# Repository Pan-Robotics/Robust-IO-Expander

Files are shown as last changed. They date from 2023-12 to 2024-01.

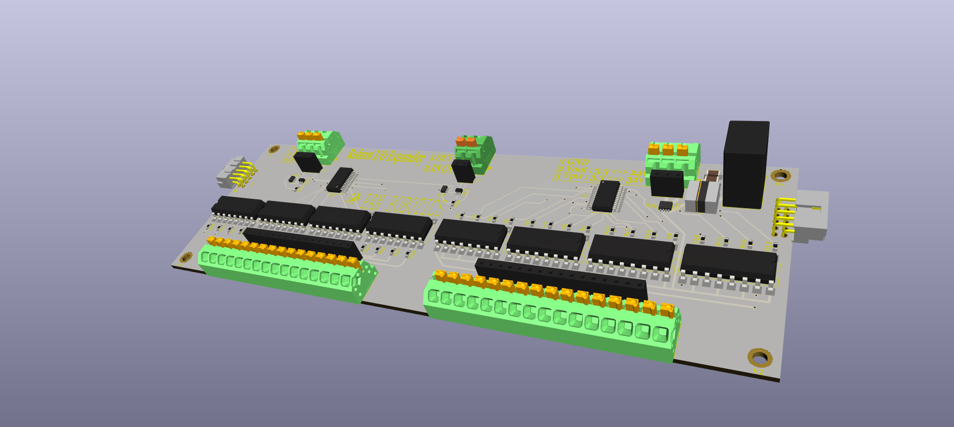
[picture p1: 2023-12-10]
Robust IO Expander/Docs/Photos/3D 4.png

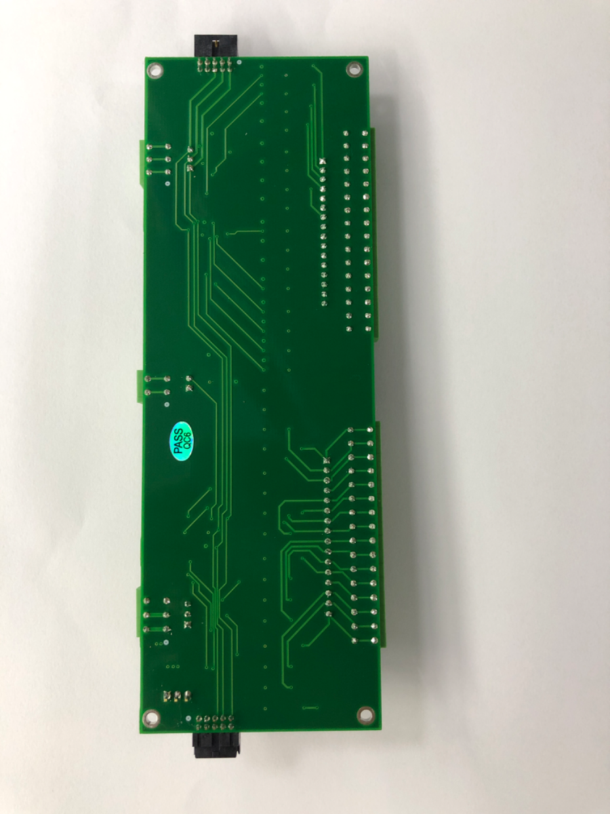
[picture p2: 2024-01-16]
Robust IO Expander/Docs/Photos/IO-Expander 3-Back.jpg

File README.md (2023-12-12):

# Robust-IO-Expander

    1. Dual MCP23S17 ICs: Harness the power of two MCP23S17 16-Bit I/O Expander ICs – one dedicated for inputs, ensuring robust data acquisition, 
    and the other exclusively for outputs, enabling precise device control.
    
    2. Galvanic Isolation with Opto Switches: Prioritize safety in your projects. Our I/O Expansion Module integrates opto switches for galvanic isolation, 
    shielding your electronics from voltage spikes and surges, ensuring secure and reliable operation.
    
    3. SPI Interface: Interact effortlessly with your system via the SPI interface. This streamlined communication protocol ensures swift and efficient data exchange, 
    allowing you to focus on the heart of your project.
    
    4. Connector Options: Tailor the module to your needs. Choose between 2.54mm header connectors for easy integration into your existing setups or Push terminals for a robust, secure connection. 
    The choice is yours, ensuring seamless compatibility with your specific project requirements.
    
    5. Effortless Expansion: Need more I/O pins? No problem! Our module is stackable, facilitating seamless expansion. 
    Connect multiple modules effortlessly to scale your projects without limitations, providing endless opportunities for your creative endeavors.
    
    6. Unparalleled Flexibility: Whether you're orchestrating automation systems, developing cutting-edge robotics, or creating interactive art installations, 
    the versatility of our I/O Expansion Module amplifies your creativity. Control motors, sensors, LEDs, and various devices effortlessly, opening doors to innovative projects.

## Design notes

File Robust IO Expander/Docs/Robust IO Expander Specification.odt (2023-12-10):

Introducing our state-of-the-art I/O Expansion Module, designed to empower your projects with seamless control and unparalleled safety. Whether you're a hobbyist, engineer, or DIY enthusiast, this module is your gateway to limitless possibilities.

Key Features:

1. Dual MCP23S17 ICs: Harness the power of two MCP23S17 16-Bit I/O Expander ICs – one dedicated for inputs, ensuring robust data acquisition, and the other exclusively for outputs, enabling precise device control.
2. Galvanic Isolation with Opto Switches: Prioritize safety in your projects. Our I/O Expansion Module integrates opto switches for galvanic isolation, shielding your electronics from voltage spikes and surges, ensuring secure and reliable operation.
3. SPI Interface: Interact effortlessly with your system via the SPI interface. This streamlined communication protocol ensures swift and efficient data exchange, allowing you to focus on the heart of your project.
4. Connector Options: Tailor the module to your needs. Choose between 2.54mm header connectors for easy integration into your existing setups or Push terminals for a robust, secure connection. The choice is yours, ensuring seamless compatibility with your specific project requirements.
5. Effortless Expansion: Need more I/O pins? No problem! Our module is stackable, facilitating seamless expansion. Connect multiple modules effortlessly to scale your projects without limitations, providing endless opportunities for your creative endeavors.
6. Unparalleled Flexibility: Whether you're orchestrating automation systems, developing cutting-edge robotics, or creating interactive art installations, the versatility of our I/O Expansion Module amplifies your creativity. Control motors, sensors, LEDs, and various devices effortlessly, opening doors to innovative projects.
7. Built to Last: Crafted from premium electronics and rigorously tested, our I/O Expansion Module is built for durability. Its robust design ensures longevity, even in demanding environments, providing a dependable foundation for your projects.
8. Expert Support: Need guidance? Have questions? We're here for you. Our dedicated team of experts (Singular) is committed to providing unmatched customer support, ensuring you receive the assistance you need at every stage of your project.

Elevate your projects with our I/O Expansion Module, featuring dedicated MCP23S17 ICs, an SPI interface for seamless interaction, and the flexibility to choose between 2.54mm header connectors and screw terminals. Experience expanded I/O capabilities and the assurance of secure, stable operation. Empower your projects – order now and unlock the true potential of your creativity!

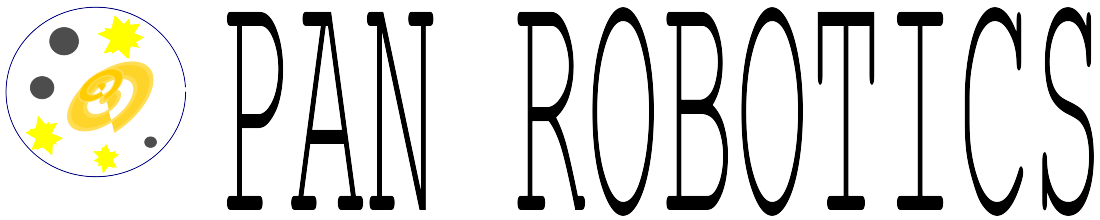
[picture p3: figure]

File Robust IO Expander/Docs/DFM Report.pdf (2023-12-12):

## HQDFM Design for Manufacture(DFM) Report

### File name: 2023-12-12

Time: 2023-12-12Layer count:4 | pcb thickness:1.60 | Quantity5
mm

Approved items

Urgent Issues

Issue Items 28

1 1

Basic Parameter Analysis | Trace Width/Spacing | 10.00/8.00mil+
| Milling Density | 45.5315m/m²
| Surface Finish Area | 14.42%
| Test Point Count | 437
| Panel Efficiency | 85.1349%

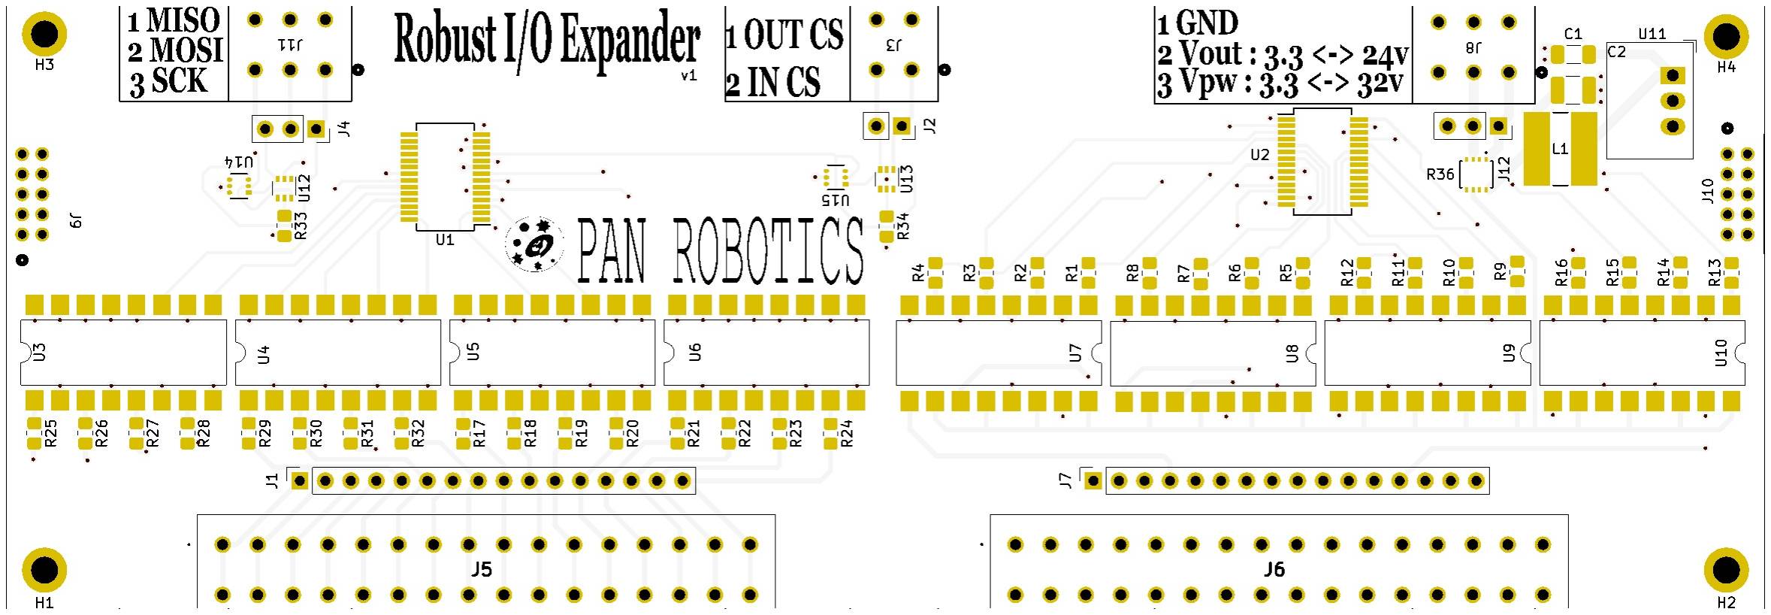
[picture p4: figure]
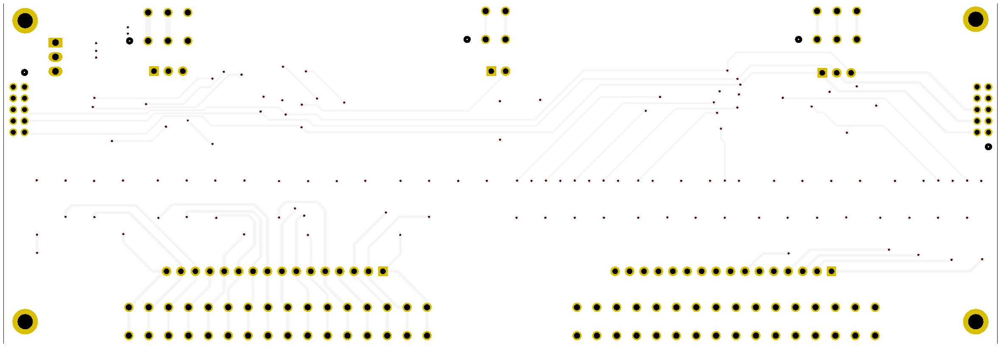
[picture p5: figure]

Type | checklist item | checklist subitem | Result
| Open/Shorts (IPC) | 1 | Fail
| Signal Integrity | 4 | Pass
| Smallest Trace Width | 1 | Pass
| Smallest Trace Spacing | 3 | Pass 178
| Pad Spacing | 2 | Pass 16 ,Fail 52
| Min pad size | 3 | Pass 88
| Hatched Copper Pour | 2 | Pass
| RingHole | 2 | Pass 280
| Drill to Copper | 5 | Pass 272
| Board Edge Clearance | 2 | Pass 160
| Pad Hole | 4 | Pass
PCB Drilling Analysis | Hole Diameter | 8 | Pass 21
| Drill Hole Spacing | 4 | Pass 3
| Drill to Board Edge | 4 | Pass 37
| Drill Hole Density | 1 | Pass
| Special Drill Holes | 2 | Pass
| Drill Hole Errors | 3 | Pass
PCB Solder Mask Analysis | Solder Mask Spacing | 2 | Pass 64
| Missing SMask Openings | 1 | Pass
| Solder Paste Area | 1 | Pass
PCB Silk Analysis | Silkscreen Spacing | 1 | Pass
ASS_component | Component Spacing | 1 | Fail
| Component to Edge | 3 | Fail
| Silk Spacing | 0 | Fail
| Pin mismatch | 2 | Fail
| Reference designator byte | 0 | Fail
| Plug-in Components | 1 | Pass

PCB Trace Analysis

ASS_Pin Analysis | Pin-to-SMD Pad | 5 | Fail
| Through-hole pins | 6 | Fail
| Press-fit pins | 4 | Fail
ASS_Pad Analysis | Chip Pad | 60 | Fail
| Solder pad traces | 4 | Pass 416 ,Fail 5
ASS_Fiducials Analysis | Fiducials | 1 | Fail
| Fiducial Mark Analysis | 3 | Pass

ID

### checklist

### item

Limits: | Value | Issue | image | Coordinate | Quan

## tity

### Level

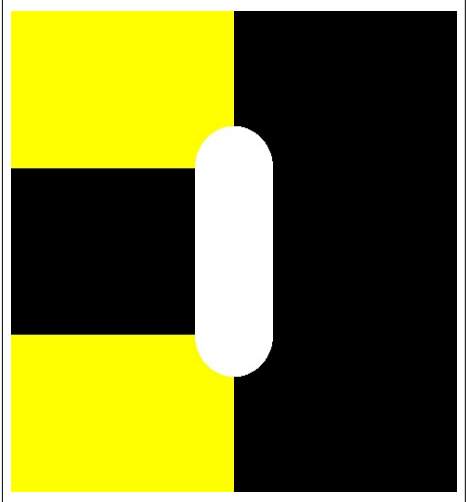
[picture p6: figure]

1

### Pad

Spacing_Pa

### d Spacing

6,8,10

0.20

mm

Pad to pad spacing for
different SMD parts of
7.87mil were detected in
your design. This could
result in incomplete solder mask dams between the
pads, thereby increasing
the risk of solder bridges during assembly, which
decrease manufacturing
efficiency and yield, and

### affect the reliability of the

boards. It is recommended
to increase the spacing to at least 8 mil for green
solder mask.
93.80,-94.04 | 52 | Warnin g

2

### Solder pad

traces_pad
_thermolys
is_smt
-,-,- | Not
| Analyz
| ed

If the wire occupies

### ≥85.85% of the solder

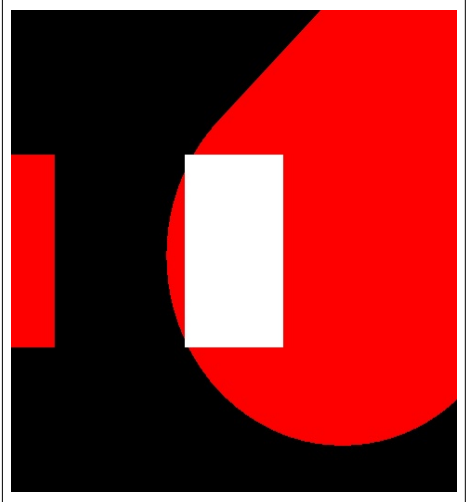
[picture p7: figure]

pad's perimeter width ratio, rapid heat dissipation and a low solder paste melting point can lead to cold
solder joints. It is
recommended to optimize
the trace routing and the
ratio of copper connected
to the solder pad.
200.11,-92.68 | 1 | Risk

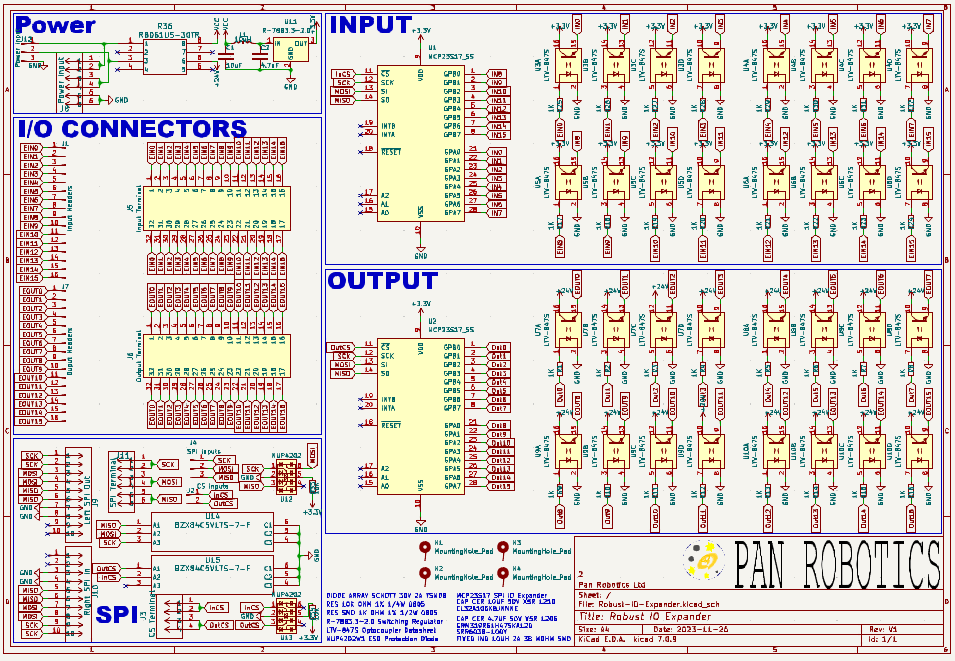
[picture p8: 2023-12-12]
Robust IO Expander/Docs/Photos/Robust IO Expander Schematic.png

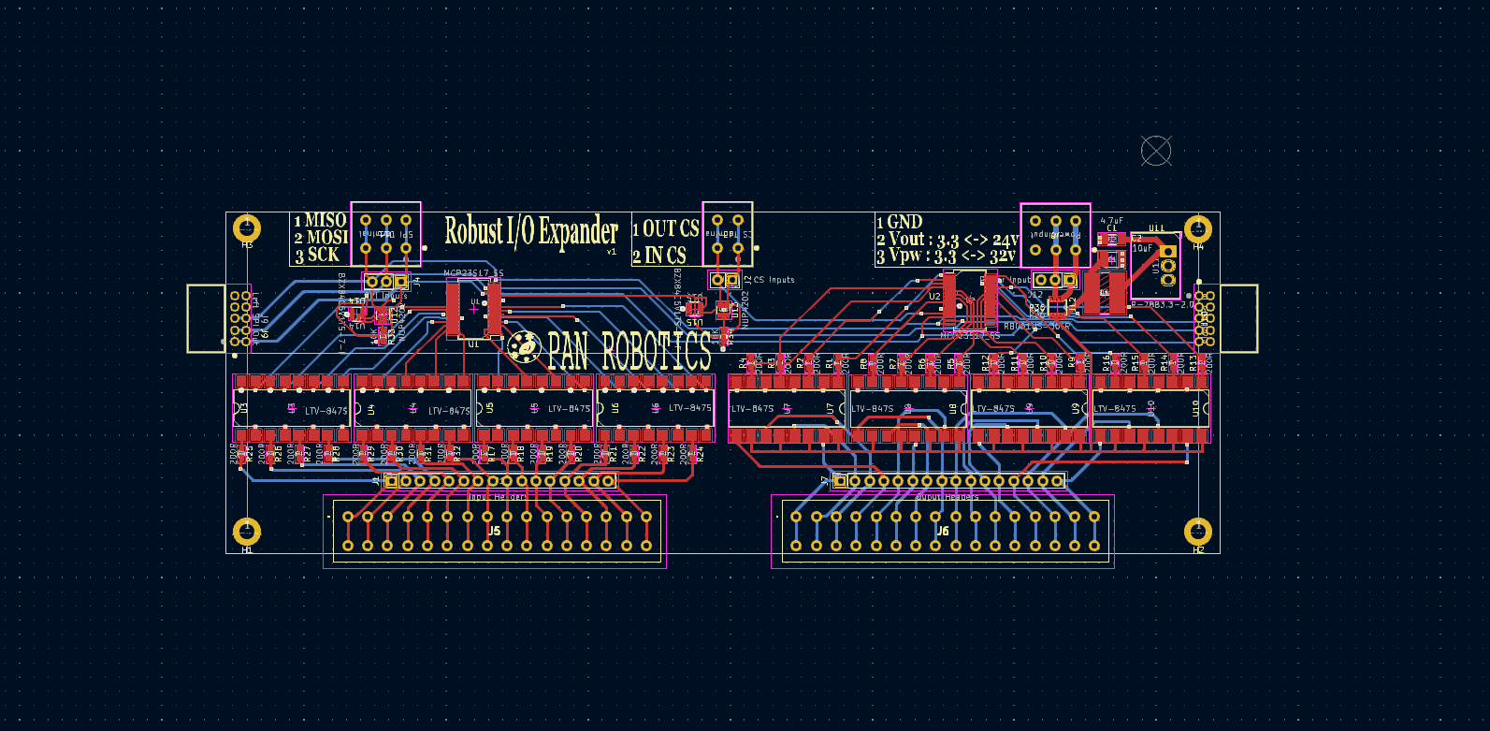
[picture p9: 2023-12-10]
Robust IO Expander/Docs/Photos/PCB 2.png

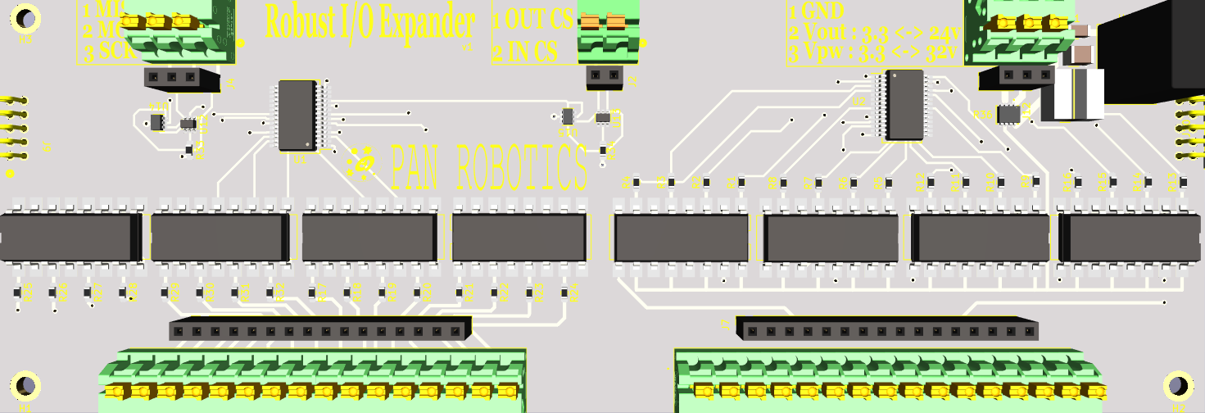
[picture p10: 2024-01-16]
Robust IO Expander/Docs/Photos/3D 5.png

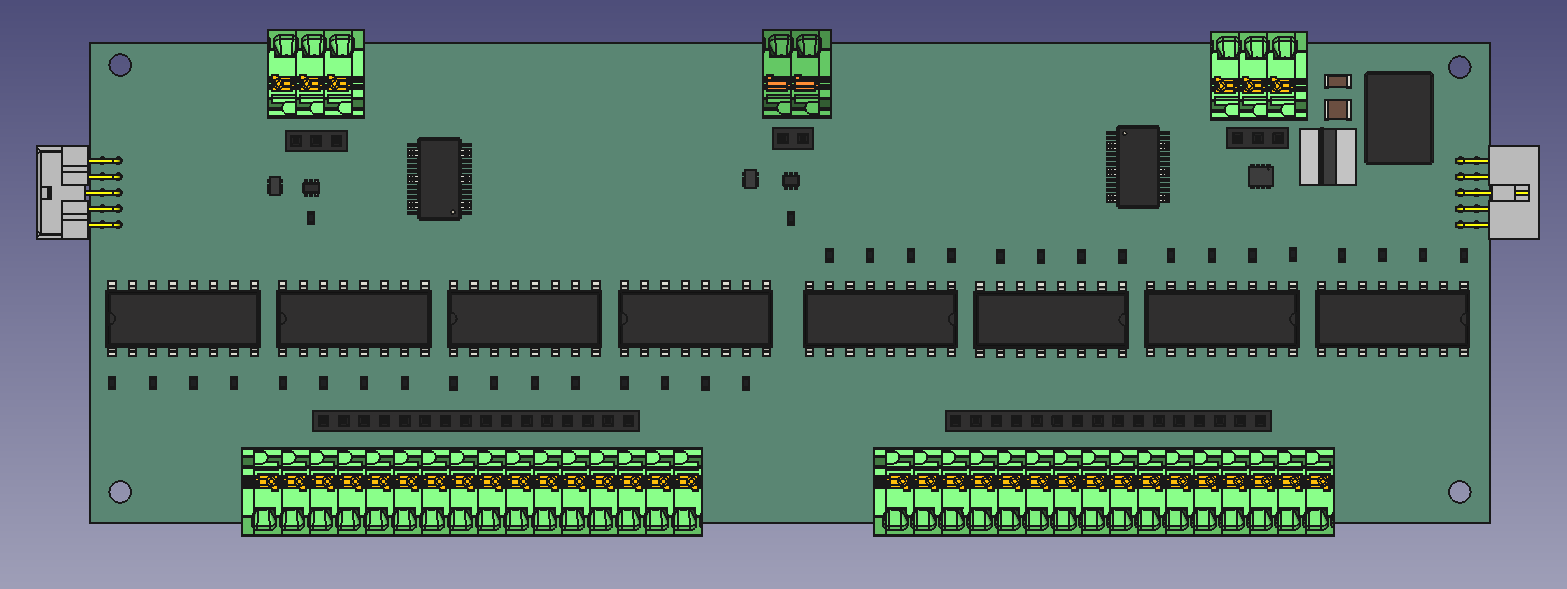
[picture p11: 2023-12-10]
Robust IO Expander/Docs/Photos/3D 1.png

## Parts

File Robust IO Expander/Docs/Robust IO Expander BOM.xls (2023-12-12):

BOM
Part | Value | Device | Package | Qty | Description | Remark
U10,U3,U4,U5,U6,U7,U8,U9 | LTV-847S | LTV-847S | SMDIP-16_W9.53mm | 8 | OPTOISOLTR 5KV 4CH TRANS 16-SMD | https://optoelectronics.liteon.com/upload/download/DS-70-96-0016/LTV-8X7%20series%20RevQ.PDF
U1,U2 | MCP23S17_SS | MCP23S17T-E/SS | SSOP-28_5.3x10.2mm_P0.65mm | 2 | I/O Expander 16 SPI 10 MHz 28-SSOP | https://ww1.microchip.com/downloads/aemDocuments/documents/APID/ProductDocuments/DataSheets/MCP23017-Data-Sheet-DS20001952.pdf
L1 | 10uH | SRR6038-100Y | IND_BOURNS_SRR6038 | 1 | 10 µH Shielded Drum Core, Wirewound Inductor 2 A 38mOhm Max Nonstandard | https://www.bourns.com/docs/Product-Datasheets/SRR6038.pdf
R1,R10,R11,R12,R13,R14,R15,R16,R17,R18,R19,R2,R20,R21,R22,R23,R24,R25,R26,R27,R28,R29,R3,R30,R31,R32,R4,R5,R6,R7,R8,R9 | 1K | CRCW08051K00FKEAHP | R_0805_2012Metric_Pad | 32 | 1 kOhms ±1% 0.5W, 1/2W Chip Resistor 0805 (2012 Metric) Automotive AEC-Q200, Pulse Withstanding Thick Film | https://www.vishay.com/docs/20043/crcwhpe3.pdf
U14,U15 | BZX84C5V1TS-7-F | BZX84C5V1TS-7-F | SOT-363_DIO | 2 | Zener Diode Array 3 Independent 5.1 V 200 mW ±6% SOT-363 | https://mm.digikey.com/Volume0/opasdata/d220001/medias/docus/812/BCX84C2V4TS-39TS.pdf
R33,R34 | 10K | RK73H2ATTD1002F | R_0805_2012Metric_Pad | 2 | RES 10K OHM 1% 1/4W 0805 | https://www.koaspeer.com/pdfs/RK73H.pdf
U12,U13 | NUP4202 | NUP4202W1T2G | SOT-363_SC-70-6 | 2 | 14.5V (Typ) Clamp 28A (8/20µs) Ipp Tvs Diode Surface Mount SC-88/SC70-6/SOT-363 | https://www.onsemi.com/pdf/datasheet/nup4202w1-d.pdf
J5,J6 | Output & Input Terminals | 1862262 | CONN_1862262 | 2 | TERM BLOCK 16POS 45DEG 3.5MM PCB | https://www.phoenixcontact.com/en-us/products/printed-circuit-board-terminal-sptaf-116-35-el-1862262?type=pdf
R36 | RB061US-30TR | RB061US-30TR | DIO_RB061U_ROM | 1 | Diode Array 2 Independent 30 V 2A Surface Mount 8-SMD | https://fscdn.rohm.com/en/products/databook/datasheet/discrete/diode/schottky_barrier/rb061us-30tr-e.pdf
C1 | 10uF | CL32A106KBJNNNE | C_1210_3225Metric_Pad | 1 | 10 µF ±10% 50V Ceramic Capacitor X5R 1210 (3225 Metric) | https://www.samsungsem.com/resources/file/global/support/product_catalog/MLCC.pdf
C2 | 4.7uF | GRM319R61H475KA12D | C_1206_3216Metric_Pad | 1 | 4.7 µF ±10% 50V Ceramic Capacitor X5R 1206 (3216 Metric) | https://search.murata.co.jp/Ceramy/image/img/A01X/G101/ENG/GRM319R61H475KA12-01.pdf
J11,J8 | Power & SPI Terminal | 1862055 | CONN_1862055 | 2 | TERM BLOCK 3POS 45DEG 3.5MM PCB | https://www.phoenixcontact.com/en-us/products/printed-circuit-board-terminal-sptaf-1-3-35-el-1862055?type=pdf
J2 | CS Headers | *choose any* | PinSocket_1x02_P2.54mm_Vertical | 1 | 2 position 2.54mm vertical female socket
J4,J12 | Power & SPI Headers | *choose any* | PinSocket_1x03_P2.54mm_Vertical | 2 | 3 position 2.54mm vertical female socket
J1, J7 | Output & Input Headers | *choose any* | PinSocket_1x16_P2.54mm_Vertical | 2 | 16 position 2.54mm vertical female socket
J3 | CS Terminal | 1862042 | CONN_1862042 | 1 | TERM BLOCK 2POS 45DEG 3.5MM PCB | https://www.phoenixcontact.com/product/pdf/api/v1/MTg2MjA0Mg?_realm=us&_locale=en-US
U11 | R-78B3.3-2.0 | R-78B3.3-2.0 | Converter_DCDC_RECOM_R-78B-2.0_THT | 1 | Linear Regulator Replacement DC DC Converter 1 Output 3.3V 2A 4.75V - 32V Input | https://recom-power.com/pdf/Innoline/R-78B-2.0.pdf
J9 | Left SPI Out | LS2-105-01-F-D-RA1 | CONN_LS2-105-01-X-D-RA1_SAI | 1 | 10 Position Connector Self Mating, Non-Gendered, Hermaphroditic Through Hole, Right Angle Gold | https://suddendocs.samtec.com/catalog_english/ls2.pdf
J10 | Right SPI In | LS2-105-01-F-D-RA2 | CONN_LS2-105-01-X-D-RA2_SAI | 1 | 10 Position Connector Self Mating, Non-Gendered, Hermaphroditic Through Hole, Right Angle Gold | https://suddendocs.samtec.com/catalog_english/ls2.pdf

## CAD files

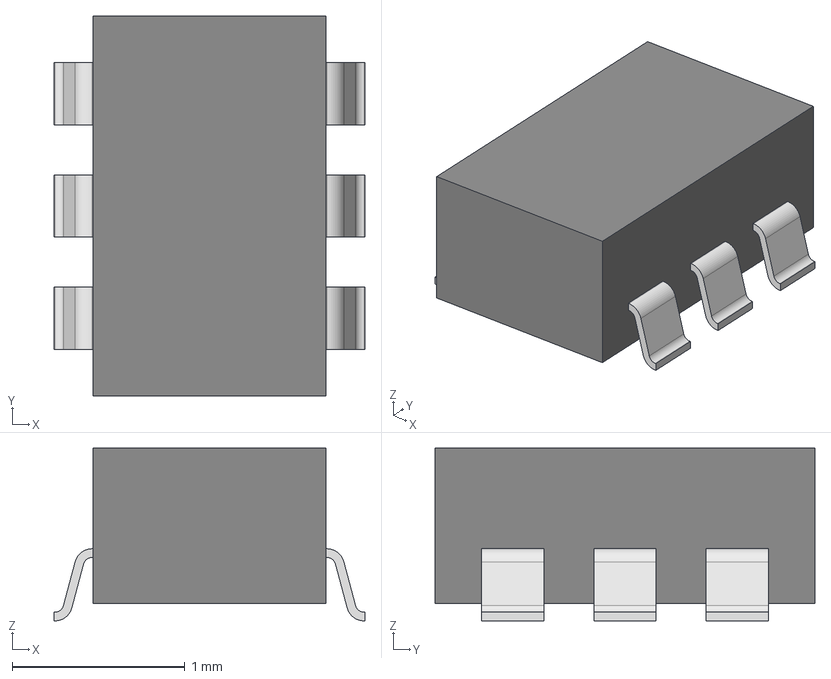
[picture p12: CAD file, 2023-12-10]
Robust IO Expander/BZX84C5V1TS_7_F/SOT-363_DIO.step
1.80 x 2.20 x 1.00 mm

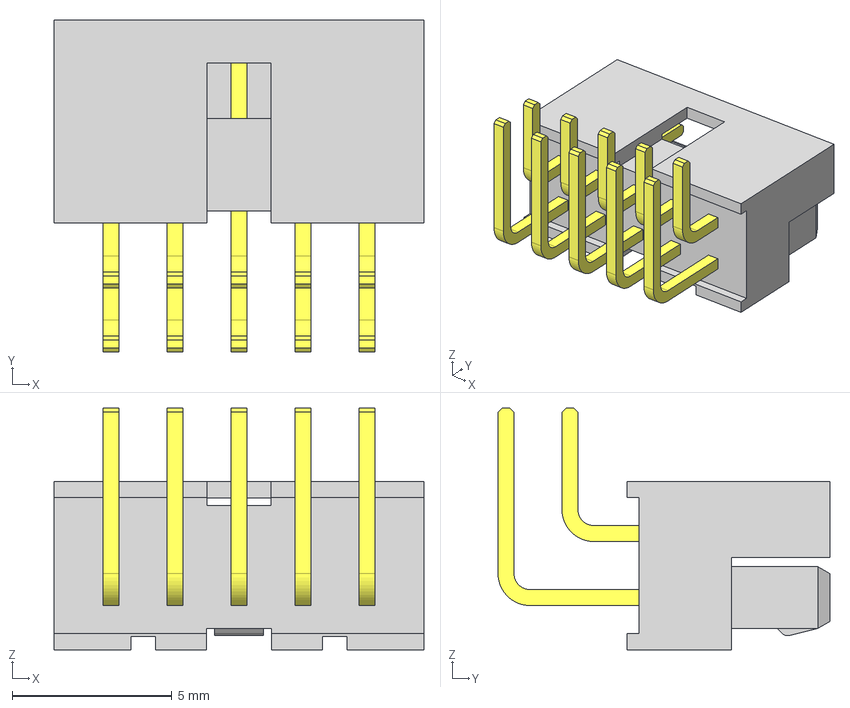
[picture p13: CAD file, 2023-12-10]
Robust IO Expander/LS2_105_01_F_D_RA1/LS2-105-01-F-D-RA1.stp
11.6 x 10.4 x 7.56 mm
T-1S13-05-01-D-RA1
LS2-105-01-D_strip

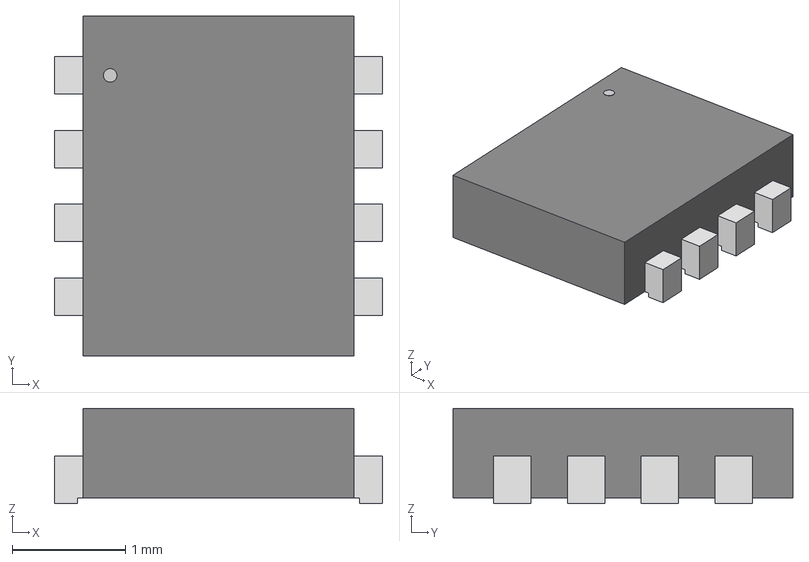
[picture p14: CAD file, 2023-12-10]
Robust IO Expander/RB061US_30TR/DIO_RB061U_ROM.step
2.90 x 3.00 x 0.841 mm

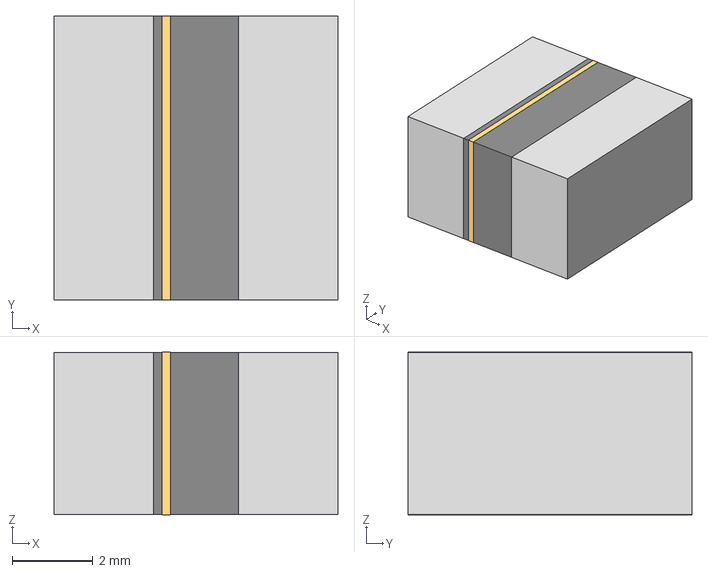
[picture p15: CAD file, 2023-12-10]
Robust IO Expander/SRR6038_100Y/IND_BOURNS_SRR6038.step
7.01 x 7.02 x 4.02 mm

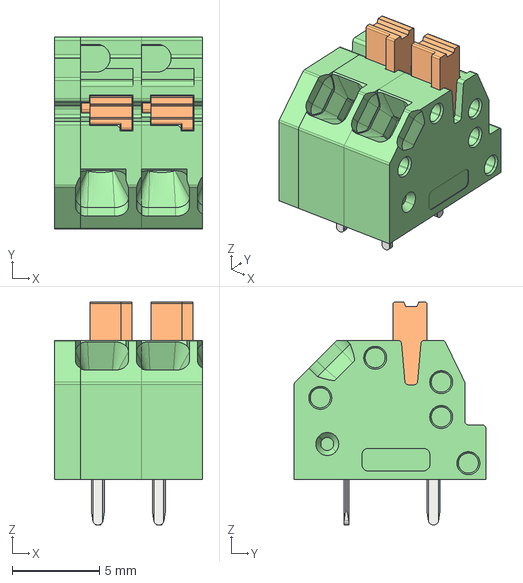
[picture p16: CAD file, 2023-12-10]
Robust IO Expander/1862042/1862042.step
8.50 x 11.0 x 12.8 mm

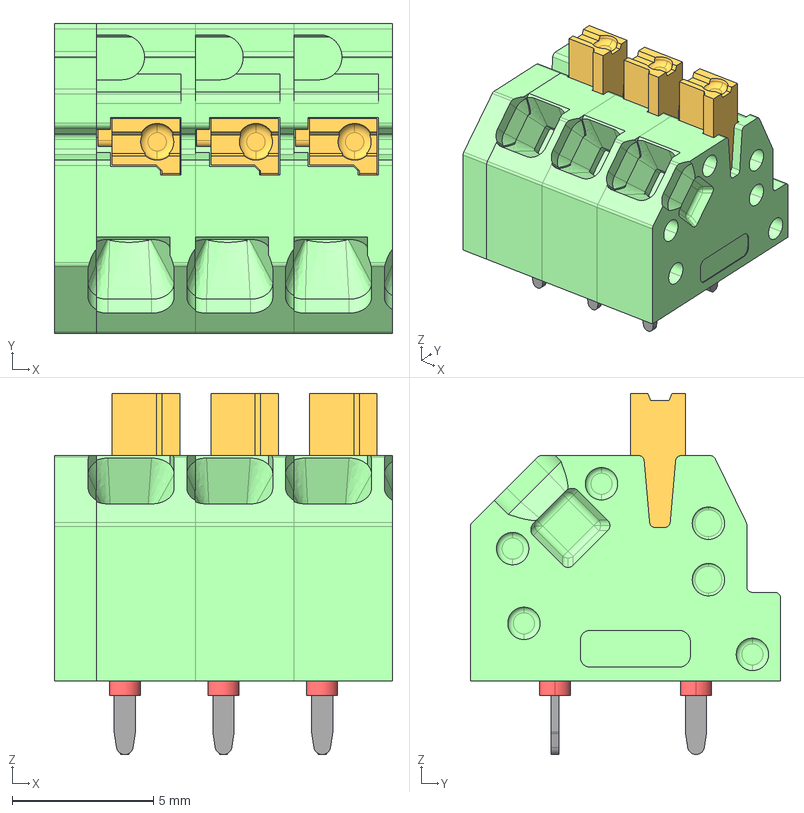
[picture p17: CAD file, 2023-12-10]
Robust IO Expander/1862055/1862055.stp
12.0 x 11.0 x 12.8 mm

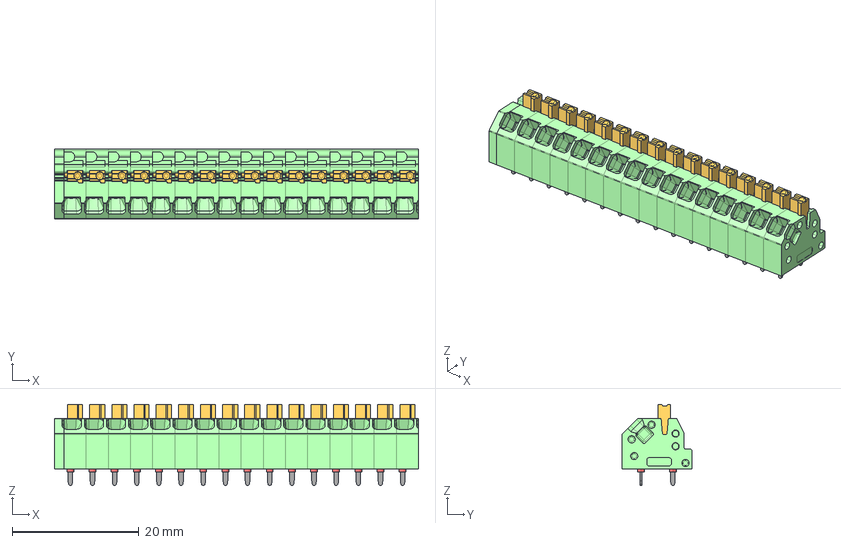
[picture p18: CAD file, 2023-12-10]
Robust IO Expander/LIB_1862262/1862262/3D/1862262.stp
57.5 x 11.0 x 12.8 mm
Bohrloch.1.1.2 x 16
Bohrloch.2.2 x 16
SPTAF_1-3.5_housing.13 x 16
SPTAF-0-DKL.1

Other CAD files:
Robust IO Expander/LS2_105_01_F_D_RA2/LS2-105-01-F-D-RA2.stp

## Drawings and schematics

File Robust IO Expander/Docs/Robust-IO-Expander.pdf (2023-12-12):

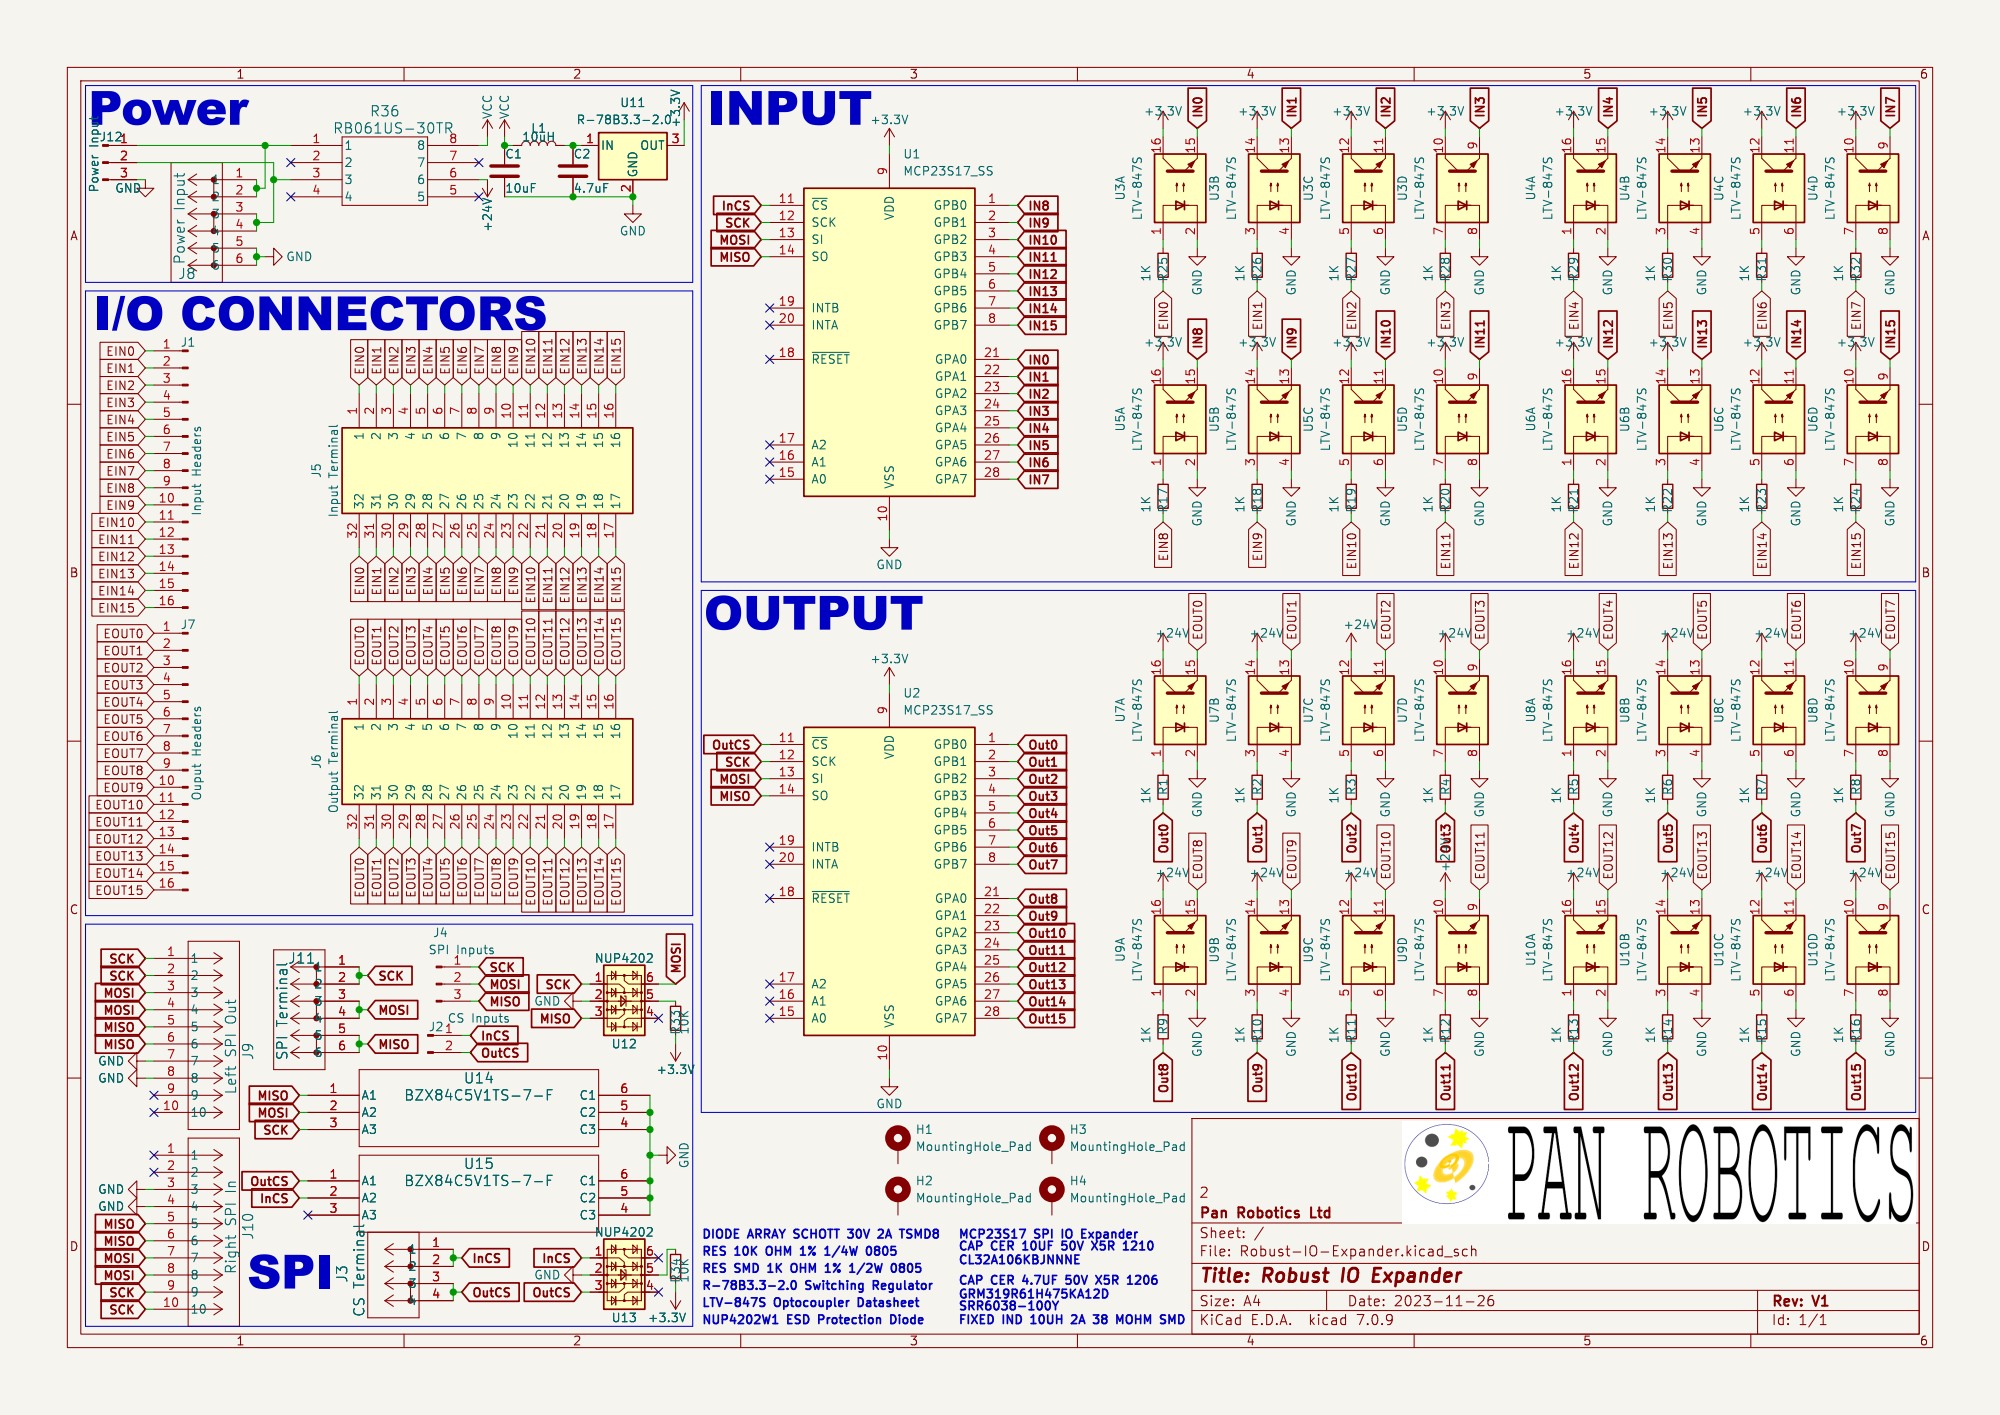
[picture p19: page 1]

4 U8B LTV-847S GND GND 1KR18 1KR19 GND R8 1K

9 J6 Output Terminal GND GND 10 7

SRR6038-100Y
FIXED IND 10UH 2A 38 MOHM SMD (https://www.bourns.com/docs/Product-Datasheets/SRR6038.pdf)

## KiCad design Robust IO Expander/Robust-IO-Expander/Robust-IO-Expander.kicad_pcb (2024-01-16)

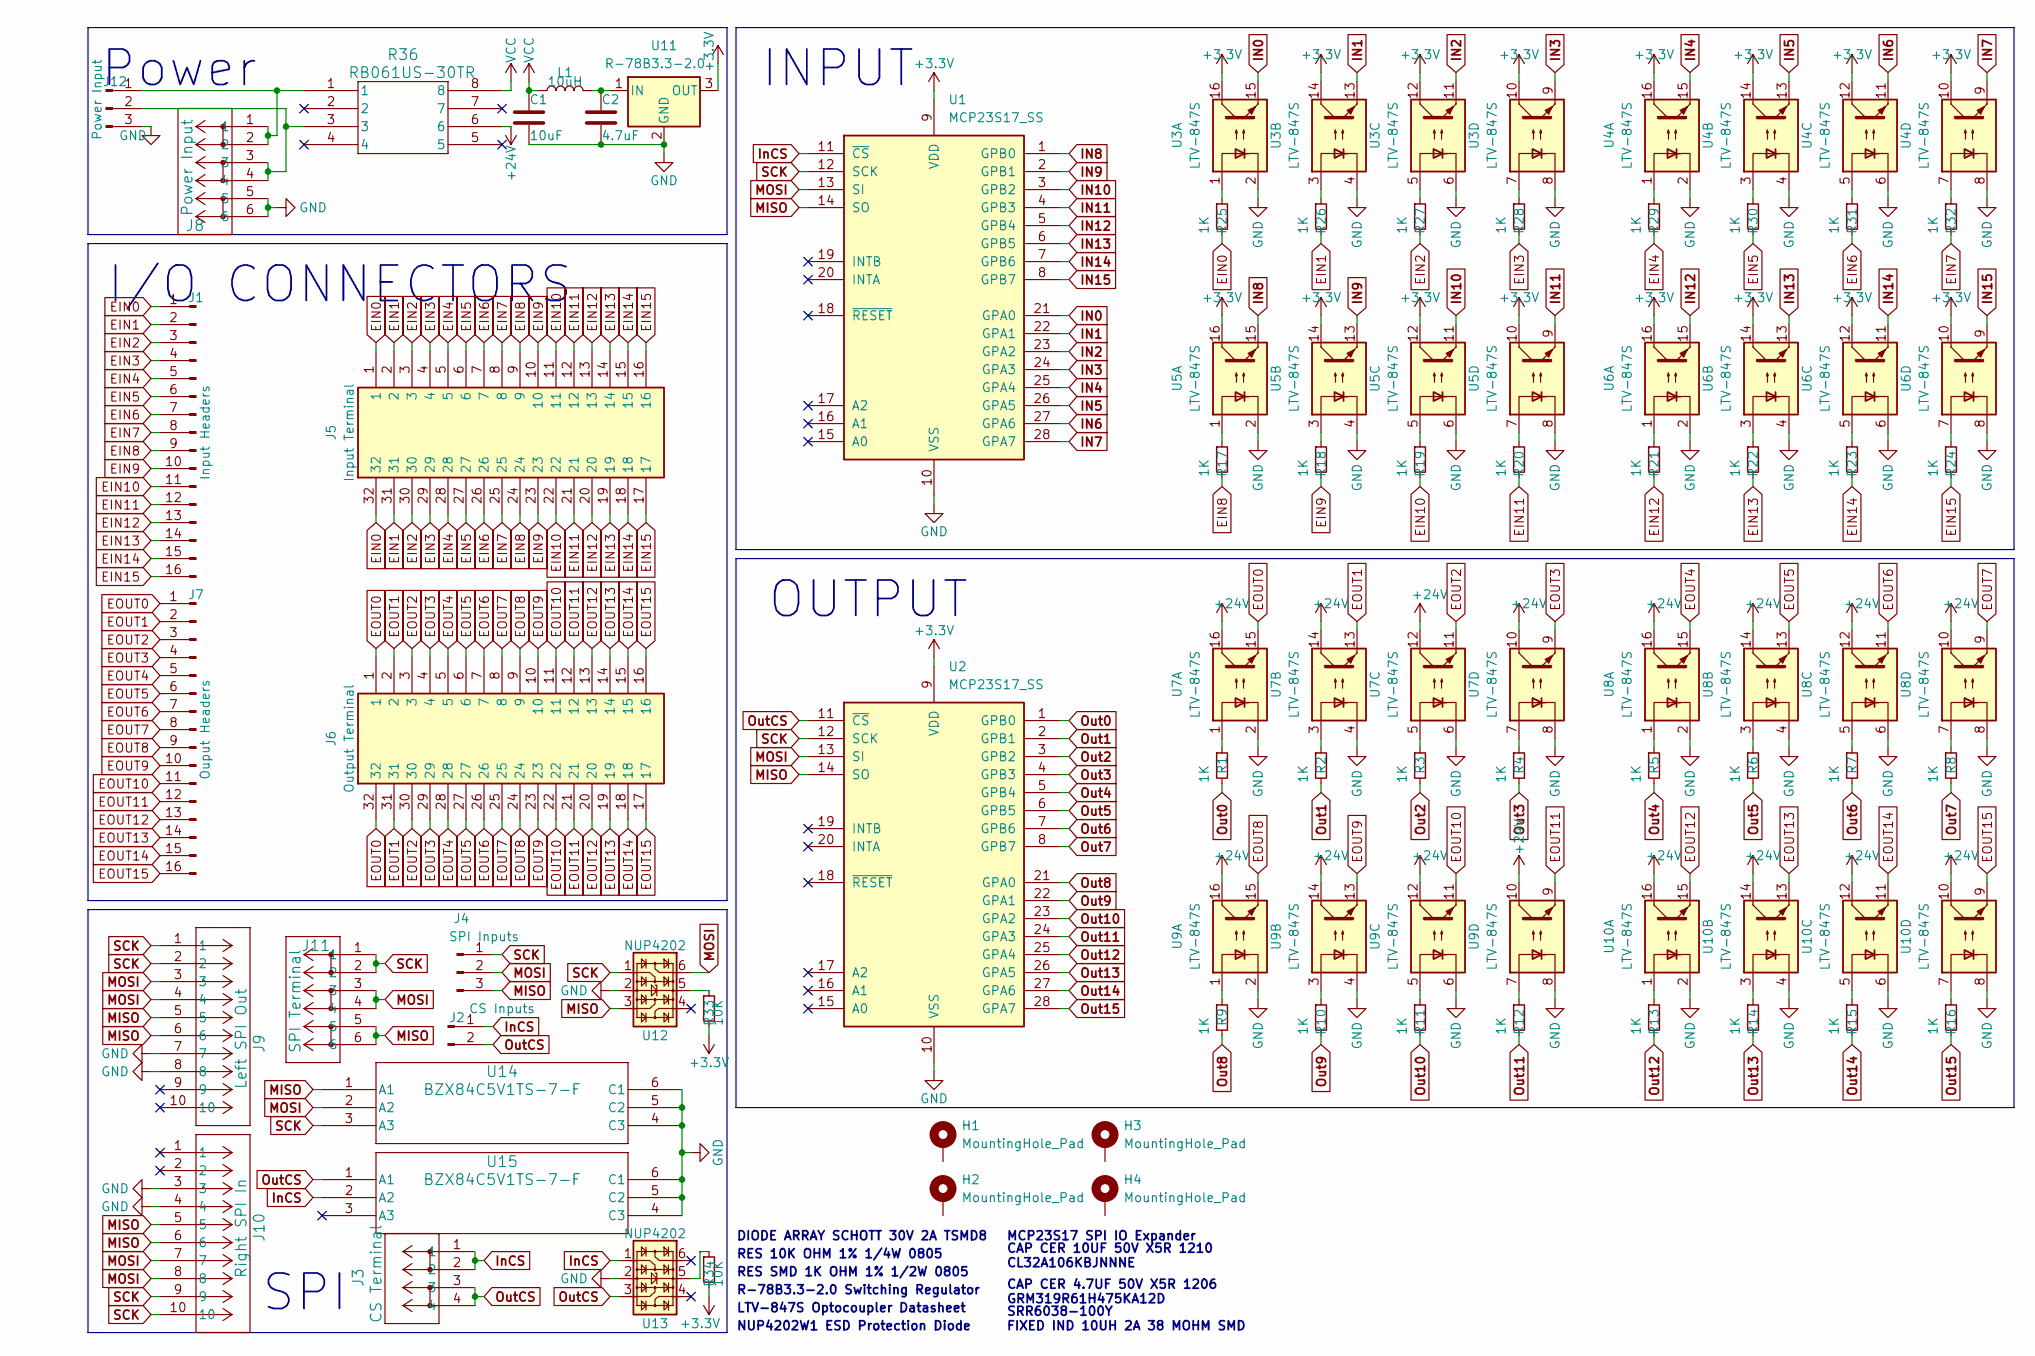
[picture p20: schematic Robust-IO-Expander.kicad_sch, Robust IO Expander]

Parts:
C1: 10uF; C_1210_3225Metric_Pad1.33x2.70mm_HandSolder
C2: 4.7uF; C_1206_3216Metric_Pad1.33x1.80mm_HandSolder
H1, H2, H3, H4: MountingHole_Pad; MountingHole_2.7mm_M2.5_ISO7380_Pad
J1: Input Headers; PinSocket_1x16_P2.54mm_Vertical
J2: CS Inputs; PinSocket_1x02_P2.54mm_Vertical
J3: CS Terminal; CONN_1862042
J4: SPI Inputs; PinSocket_1x03_P2.54mm_Vertical
J5: Input Terminal; 1862262; Mouser Part Number 651-1862262
J6: Output Terminal; 1862262; Mouser Part Number 651-1862262
J7: Ouput Headers; PinSocket_1x16_P2.54mm_Vertical
J8: Power Input; CONN_1862055
J9: Left SPI Out; CONN_LS2-105-01-X-D-RA1_SAI
J10: Right SPI In; CONN_LS2-105-01-X-D-RA2_SAI
J11: SPI Terminal; CONN_1862055
J12: Power Input; PinSocket_1x03_P2.54mm_Vertical
L1: 10uH; IND_BOURNS_SRR6038
R1, R2, R3, R4, R5, R6, R7, R8, R9, R10, R11, R12, R13, R14, R15, R16, R17, R18, R19, R20, R21, R22, R23, R24, R25, R26, R27, R28, R29, R30, R31, R32: 1K; R_0805_2012Metric_Pad1.20x1.40mm_HandSolder
R33, R34: 10K; R_0805_2012Metric_Pad1.20x1.40mm_HandSolder
R36: RB061US-30TR; DIO_RB061U_ROM
U1, U2: MCP23S17_SS; SSOP-28_5.3x10.2mm_P0.65mm
U3, U4, U5, U6, U7, U8, U9, U10: LTV-847S; SMDIP-16_W9.53mm
U11: R-78B3.3-2.0; Converter_DCDC_RECOM_R-78B-2.0_THT
U12, U13: NUP4202; SOT-363_SC-70-6
U14, U15: BZX84C5V1TS-7-F; SOT-363_DIO

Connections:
+3.3V: R33.2, R34.2, U1.9 (VDD), U2.9 (VDD), U3.10, U3.12, U3.14, U3.16, U4.10, U4.12, U4.14, U4.16, U5.10, U5.12, U5.14, U5.16, U6.10, U6.12, U6.14, U6.16, U11.3 (OUT)
+24V: R36.6, U7.10, U7.12, U7.14, U7.16, U8.10, U8.12, U8.14, U8.16, U9.10, U9.12, U9.14, U9.16, U10.10, U10.12, U10.14, U10.16
EIN0: J1.1, J5.1, J5.32, R25.2
EIN1: J1.2, J5.2, J5.31, R26.2
EIN2: J1.3, J5.3, J5.30, R27.2
EIN3: J1.4, J5.4, J5.29, R28.2
EIN4: J1.5, J5.5, J5.28, R29.2
EIN5: J1.6, J5.6, J5.27, R30.2
EIN6: J1.7, J5.7, J5.26, R31.2
EIN7: J1.8, J5.8, J5.25, R32.2
EIN8: J1.9, J5.9, J5.24, R17.2
EIN9: J1.10, J5.10, J5.23, R18.2
EIN10: J1.11, J5.11, J5.22, R19.2
EIN11: J1.12, J5.12, J5.21, R20.2
EIN12: J1.13, J5.13, J5.20, R21.2
EIN13: J1.14, J5.14, J5.19, R22.2
EIN14: J1.15, J5.15, J5.18, R23.2
EIN15: J1.16, J5.16, J5.17, R24.2
EOUT0: J6.1, J6.32, J7.1, U7.15
EOUT1: J6.2, J6.31, J7.2, U7.13
EOUT2: J6.3, J6.30, J7.3, U7.11
EOUT3: J6.4, J6.29, J7.4, U7.9
EOUT4: J6.5, J6.28, J7.5, U8.15
EOUT5: J6.6, J6.27, J7.6, U8.13
EOUT6: J6.7, J6.26, J7.7, U8.11
EOUT7: J6.8, J6.25, J7.8, U8.9
EOUT8: J6.9, J6.24, J7.9, U9.15
EOUT9: J6.10, J6.23, J7.10, U9.13
EOUT10: J6.11, J6.22, J7.11, U9.11
EOUT11: J6.12, J6.21, J7.12, U9.9
EOUT12: J6.13, J6.20, J7.13, U10.15
EOUT13: J6.14, J6.19, J7.14, U10.13
EOUT14: J6.15, J6.18, J7.15, U10.11
EOUT15: J6.16, J6.17, J7.16, U10.9
GND: C1.2, C2.2, J8.5, J8.6, J9.7, J9.8, J10.3, J10.4, J12.3, U1.10 (VSS), U2.10 (VSS), U3.2, U3.4, U3.6, U3.8, U4.2, U4.4, U4.6, U4.8, U5.2, U5.4, U5.6, U5.8, U6.2, U6.4, U6.6, U6.8, U7.2, U7.4, U7.6, U7.8, U8.2, U8.4, U8.6, U8.8, U9.2, U9.4, U9.6, U9.8, U10.2, U10.4, U10.6, U10.8, U11.2 (GND), U12.2, U13.2, U14.4 (C3), U14.5 (C2), U14.6 (C1), U15.4 (C3), U15.5 (C2), U15.6 (C1)
IN0: U1.21 (GPA0), U3.15
IN1: U1.22 (GPA1), U3.13
IN2: U1.23 (GPA2), U3.11
IN3: U1.24 (GPA3), U3.9
IN4: U1.25 (GPA4), U4.15
IN5: U1.26 (GPA5), U4.13
IN6: U1.27 (GPA6), U4.11
IN7: U1.28 (GPA7), U4.9
IN8: U1.1 (GPB0), U5.15
IN9: U1.2 (GPB1), U5.13
IN10: U1.3 (GPB2), U5.11
IN11: U1.4 (GPB3), U5.9
IN12: U1.5 (GPB4), U6.15
IN13: U1.6 (GPB5), U6.13
IN14: U1.7 (GPB6), U6.11
IN15: U1.8 (GPB7), U6.9
InCS: J2.1, J3.1, J3.2, U1.11 (~CS), U13.1, U15.2 (A2)
MISO: J4.3, J9.5, J9.6, J10.5, J10.6, J11.5, J11.6, U1.14 (SO), U2.14 (SO), U12.3, U14.1 (A1)
MOSI: J4.2, J9.3, J9.4, J10.7, J10.8, J11.3, J11.4, U1.13 (SI), U2.13 (SI), U12.6, U14.2 (A2)
unnamed: J8.1, J8.2, J12.1, R36.1
unnamed: J8.3, J8.4, J12.2, R36.3
unnamed: R1.1, U7.1
unnamed: R2.1, U7.3
unnamed: R3.1, U7.5
unnamed: R4.1, U7.7
unnamed: R5.1, U8.1
unnamed: R6.1, U8.3
unnamed: R7.1, U8.5
unnamed: R8.1, U8.7
unnamed: R9.1, U9.1
unnamed: R10.1, U9.3
unnamed: R11.1, U9.5
unnamed: R12.1, U9.7
unnamed: R13.1, U10.1
unnamed: R14.1, U10.3
unnamed: R15.1, U10.5
unnamed: R16.1, U10.7
unnamed: R17.1, U5.1
unnamed: R18.1, U5.3
unnamed: R19.1, U5.5
unnamed: R20.1, U5.7
unnamed: R21.1, U6.1
unnamed: R22.1, U6.3
unnamed: R23.1, U6.5
unnamed: R24.1, U6.7
unnamed: R25.1, U3.1
unnamed: R26.1, U3.3
unnamed: R27.1, U3.5
unnamed: R28.1, U3.7
unnamed: R29.1, U4.1
unnamed: R30.1, U4.3
unnamed: R31.1, U4.5
unnamed: R32.1, U4.7
unnamed: R33.1, U12.5
unnamed: R34.1, U13.5
unnamed: C2.1, L1.2, U11.1 (IN)
Out0: R1.2, U2.1 (GPB0)
Out1: R2.2, U2.2 (GPB1)
Out2: R3.2, U2.3 (GPB2)
Out3: R4.2, U2.4 (GPB3)
Out4: R5.2, U2.5 (GPB4)
Out5: R6.2, U2.6 (GPB5)
Out6: R7.2, U2.7 (GPB6)
Out7: R8.2, U2.8 (GPB7)
Out8: R9.2, U2.21 (GPA0)
Out9: R10.2, U2.22 (GPA1)
Out10: R11.2, U2.23 (GPA2)
Out11: R12.2, U2.24 (GPA3)
Out12: R13.2, U2.25 (GPA4)
Out13: R14.2, U2.26 (GPA5)
Out14: R15.2, U2.27 (GPA6)
Out15: R16.2, U2.28 (GPA7)
OutCS: J2.2, J3.3, J3.4, U2.11 (~CS), U13.3, U15.1 (A1)
SCK: J4.1, J9.1, J9.2, J10.9, J10.10, J11.1, J11.2, U1.12 (SCK), U2.12 (SCK), U12.1, U14.3 (A3)
VCC: C1.1, L1.1, R36.8

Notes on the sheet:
DIODE ARRAY SCHOTT 30V 2A TSMD8
RES SMD 1K OHM 1% 1/2W 0805
CAP CER 10UF 50V X5R 1210 CL32A106KBJNNNE
INPUT
NUP4202W1 ESD Protection Diode
SRR6038-100Y FIXED IND 10UH 2A 38 MOHM SMD
R-78B3.3-2.0 Switching Regulator
RES 10K OHM 1% 1/4W 0805
LTV-847S Optocoupler Datasheet
I/O CONNECTORS
CAP CER 4.7UF 50V X5R 1206 GRM319R61H475KA12D
OUTPUT
SPI
Power
MCP23S17 SPI IO Expander

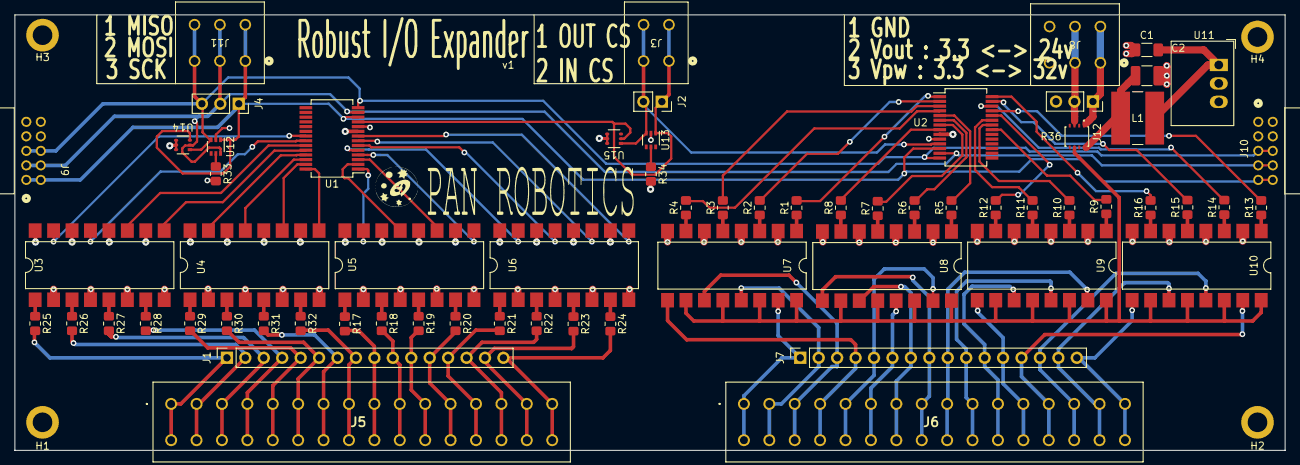
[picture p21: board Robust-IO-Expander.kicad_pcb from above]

Board: 4 copper layers, 175.0 x 60.0 mm, 69 parts (0 on the bottom side), 110 nets.

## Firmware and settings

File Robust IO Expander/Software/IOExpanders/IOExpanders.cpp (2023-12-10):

#include "IOExpanders.h"

IOExpanders::IOExpanders() : spi_settings(1000000, MSBFIRST, SPI_MODE0)
{
	enabled = false;
	number_of_expanders = 0;
	last_used_chip = 0;
	last_read_write = 0;
	
	// Clear expanders
	for ( uint8_t i = 0; i < MAX_NUMBER_EXPANDERS; i++ )
	{
		expanders[i].enabled = false;
	}
};

/*
 * Add an IO Expander chip to the list
 */
void IOExpanders::Add( uint8_t _address, uint8_t _chip_select_pin )
{
	// Setup the data structure
	expanders[_address].enabled = true;
	expanders[_address].chip_select_pin = _chip_select_pin;
	expanders[_address].pin_mode = 0xFFFF;
	expanders[_address].pullup_mode = 0x0000;
	//expanders[_address].output_cache = 0x0000;
	//expanders[_address].has_output_changed = false;
	expanders[_address].input_cache = 0x0000;
	
	// Clear write cue
	for ( uint8_t j = 0; j < MAX_NUMBER_WRITES; j++ )
	{
		expanders[_address].write_cue[j] = 0x0000;
	}
	expanders[_address].write_cue_index = 0;
	expanders[_address].last_write = 0x0000;
	
	// Setup the pins
	pinMode( _chip_select_pin, OUTPUT ); // Set SlaveSelect pin as an output
	digitalWriteFast( _chip_select_pin, 1 ); // Set SlaveSelect HIGH (chip de-selected)
	
	// Enable the chip
	ByteWrite( _address, MSG_IOCON, ADDR_ENABLE);
}

/*
 * Start listening to the expanders
 */
void IOExpanders::Enable( bool _enabled )
{
	enabled = _enabled;
}

/*
 * Called every cycle
 */
void IOExpanders::Tick()
{
	// Are we enabled?
	if (!enabled) return;
	
	// 1khz
	if ( millis() - last_read_write < 10 ) return;
	//if ( millis() - last_read_write < 1000 ) return;
	last_read_write = millis();
	
	// Loop through expanders
	uint8_t i = last_used_chip+1;
	uint8_t iterations = 0;
	while ( i < MAX_NUMBER_EXPANDERS && iterations < 2 )
	{
		// Hit the end and didn't trigger
		if (i >= MAX_NUMBER_EXPANDERS-1)
		{
			i = 0;
			iterations++;
		}
		
		// In use?
		if (expanders[i].enabled)
		{
			// Do we need to write?
			if ( expanders[i].write_cue_index > 0 )
			{
				// Send new write data
				WordWrite( i, MSG_GPIOA, expanders[i].write_cue[0] );
				expanders[i].last_write = expanders[i].write_cue[0];
				
				// Shuffle the buffer
				//  It holds the history so we only shuffle it when writing into it
				for ( uint8_t j = 0; j < MAX_NUMBER_WRITES-1; j++ ) {
					expanders[i].write_cue[j] = expanders[i].write_cue[j+1];
				}
				
				// Reduce cue length
				expanders[i].write_cue_index--;
				
				break; // Don't read
			}
			

			// Read the current state
			// This function will read all 16 bits of I/O, and return them as a word in the format 0x(portB)(portA)
			expanders[i].input_cache = 0;                   		// Initialize a variable to hold the read values to be returned
			
			SPI.beginTransaction( spi_settings );

			digitalWriteFast( expanders[i].chip_select_pin, 0 );	// Take slave-select low
				delayMicroseconds(chipSelectWaitMs);
				SPI.transfer( OPCODER | (i << 1) );						// Send the MCP23S17 opcode, chip address, and read bit
				SPI.transfer( MSG_GPIOA );								// Send the register we want to read
				expanders[i].input_cache = SPI.transfer(0x00);			// Send any byte, the function will return the read value (register address pointer will auto-increment after write)
				expanders[i].input_cache |= (SPI.transfer(0x00) << 8);	// Read in the "high byte" (portB) and shift it up to the high location and merge with the "low byte"
			digitalWriteFast( expanders[i].chip_select_pin, 1 );	// Take slave-select high
			delayMicroseconds(chipSelectWaitMs);

			SPI.endTransaction();
			
			/*
			Serial.print( "(" );
			Serial.print( i );
			Serial.print( ") Read " );
			Serial.println( expanders[i].input_cache );
			*/
			
			break;

		}
		
		// Increase
		i++;
	}
	
	// Update the last used chip
	last_used_chip = i;
}

/*
 * Sets the mode (input or output) of all I/O pins at once 
 */
void IOExpanders::PinMode( uint8_t id, unsigned int mode )
{
	WordWrite( id, MSG_IODIRA, mode ); // Call the the generic word writer with start register and the mode cache
	expanders[id].pin_mode = mode;
}

/*
 * Selects internal 100k input pull-up of all I/O pins at once
 */
void IOExpanders::PullupMode( uint8_t id, unsigned int mode )
{
	WordWrite( id, MSG_GPPUA, mode );
	expanders[id].pullup_mode = mode;
}

/*
 * Write a byte to a given SPI Expander
 */
void IOExpanders::ByteWrite( uint8_t id, uint8_t reg, uint8_t value ) {
	// Accept the register and byte
	SPI.beginTransaction( spi_settings );
	
	digitalWriteFast( expanders[id].chip_select_pin, 0 );						// Begin SPI conversation
		delayMicroseconds(chipSelectWaitMs);
		SPI.transfer( (OPCODEW | id << 1) );	// Send the MCP23S17 opcode, chip address, and write bit
		SPI.transfer( reg );
		SPI.transfer( value );														// Send the byte
	digitalWriteFast( expanders[id].chip_select_pin, 1 );						// Terminate SPI conversation
	delayMicroseconds(chipSelectWaitMs);

	SPI.endTransaction();
}

/*
 * Write a word to a given SPI Expander
 */
void IOExpanders::WordWrite( uint8_t id, uint8_t reg, unsigned int word ) {
	// Accept the start register and word 
	SPI.beginTransaction( spi_settings );
	
	digitalWriteFast( expanders[id].chip_select_pin, 0 );						// Take slave-select low
		delayMicroseconds(chipSelectWaitMs);
		SPI.transfer( OPCODEW | (id << 1) );	// Send the MCP23S17 opcode, chip address, and write bit
		SPI.transfer( reg );														// Send the register we want to write 
		SPI.transfer( (uint8_t) (word) );                      						// Send the low byte (register address pointer will auto-increment after write)
		SPI.transfer( (uint8_t) (word >> 8) );                 						// Shift the high byte down to the low byte location and send
	digitalWriteFast( expanders[id].chip_select_pin, 1 );						// Take slave-select high
	delayMicroseconds(chipSelectWaitMs);
	
	SPI.endTransaction();
}

/*
 * Change the state of a given pin
 */
/*
void IOExpanders::Write( uint8_t id, uint8_t pin, uint8_t value, bool force )
{
	// Valid pin?
	if ( pin < 1 || pin > 16 ) return;

	unsigned int output_cache = expanders[id].output_cache;
	if (value) {
		expanders[id].output_cache |= 1 << (pin - 1);
	} else {
		expanders[id].output_cache &= ~(1 << (pin - 1));
	}

	expanders[id].has_output_changed = false;
	if ( expanders[id].output_cache != output_cache ) expanders[id].has_output_changed = true;

	
	//Serial.print( "Initial Write " );
	//Serial.println( expanders[id].output_cache );
	//if (expanders[id].has_output_changed)
	//{
	//	Serial.println( "Changed" );
	//}
	
				
	// Write this straight away?
	if (force) WordWrite(id, MSG_GPIOA, expanders[id].output_cache);
}
*/
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

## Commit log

2023-09-19 New Robust IO Expander Device
    AD 19/09/23: Schematic for Opto-isolated SPI IO Expander chip Added
    [Robust-IO-Expander.kicad_pcb, Robust-IO-Expander.kicad_sch]
2023-10-09 update
    AD 09/10/23
    finished schematic and all components on board
    [Robust-IO-Expander.kicad_pcb, Robust-IO-Expander.kicad_sch]
2023-10-15 Layout change
    AD 15/10/23: Add Screw terminals everywhere
    ESD Protection on IO and SPI Inputs
    3.3v Regulator for IO power
    [Robust-IO-Expander.kicad_pcb, Robust-IO-Expander.kicad_sch]
2023-12-10 Design Complete
    AD 10/12/23:
    Design Finalised
    BOM Created
    Gerber and POS Files Generate
    [1862042.step, 1862055.stp, 1862262.stp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]
2023-12-12 Updates
    AD 12/11/23
    1K Resistors inserted for 200R
    0603 components Error correct to 0805
    Post DFM Analysis Changes
    [BOM-Robust-IO-Expander.csv, Robust IO Expander BOM.xls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]
2024-01-16 Clerical and Image Updates
    [Robust-IO-Expander.kicad_pcb]

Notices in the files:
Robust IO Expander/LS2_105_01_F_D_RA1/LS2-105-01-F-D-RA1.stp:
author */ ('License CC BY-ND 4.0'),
